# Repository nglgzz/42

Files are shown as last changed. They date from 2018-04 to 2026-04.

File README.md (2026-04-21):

# 42 Keyboard

A mechanical keyboard with 42 keys.

## Features

- 40% – Each key is at most one unit of distance from where the finger that
  should press it rests. In other words there's no awkward reaching for keys
  that are placed far from the home row.
- Staggered columns - Because a comfortable keyboard should follow the shape of
  your hands.
- Low profile - The PCB supports Choc (PG1350) switch mounts as well as Cherry MX/Alps.

## Pics

- Finished keyboard
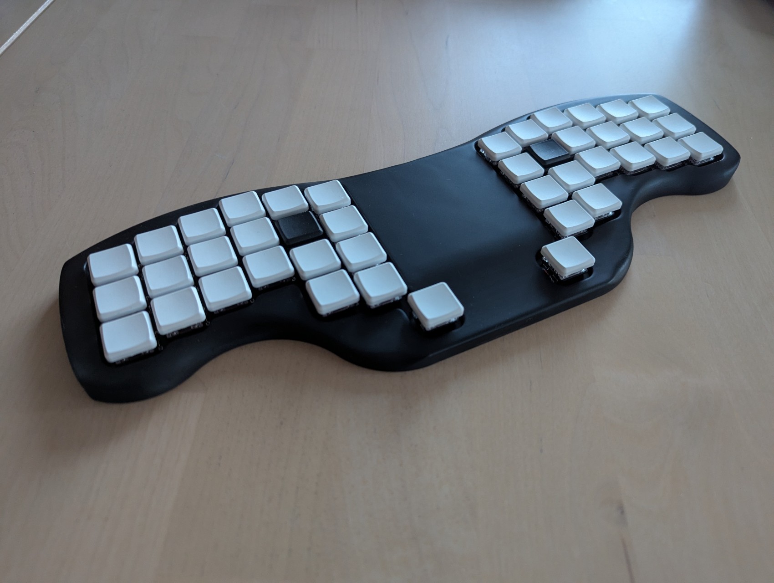
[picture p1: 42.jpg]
  <br/>
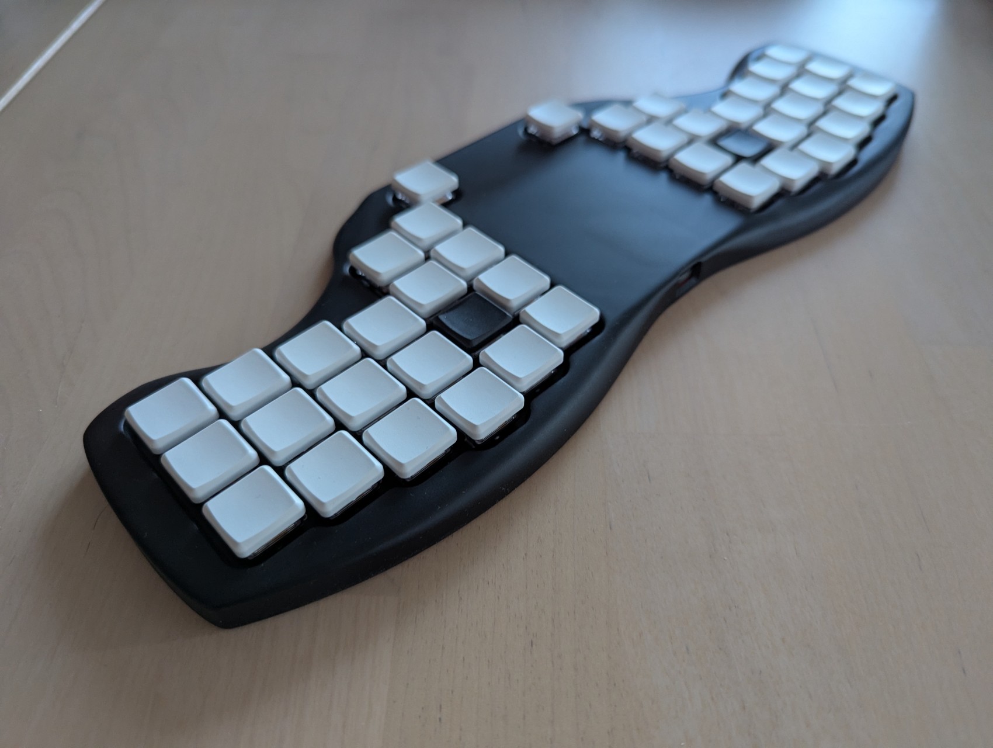
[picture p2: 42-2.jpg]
  <br/>
- PCB
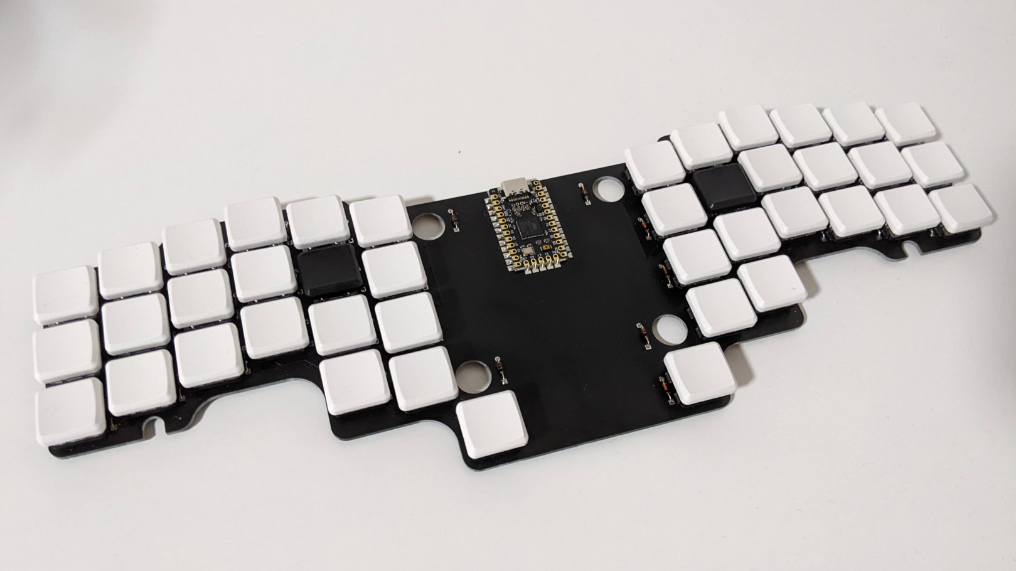
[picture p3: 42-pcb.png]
v3.1 PCB picture
  <br/>

## Project Structure

- [Build](./build/README.md) – Build log, bill of materials, tips on where to
  source parts, assembling tips, learning resources I used while designing this
  keyboard.

- [Case](./case/README.md) – Fusion 360 project and STL files for 3D printing
  the enclosure.

- [Firmware](./firmware/README.md) – QMK configuration. There is a Makefile to
  build and load the firmware.

- [PCB](./pcb/README.md) – Kicad project and Gerber files for manufacturing the
  circuit board.

## Why?

In January 2018 I wanted a keyboard with a specific set of features. The
simplest options to get that keyboard were to wait for a group-buy or build my
own. Waiting time and costs for both options seemed similar, so I went with the
option where I would learn the most.

Needs and knowledge changed over time, so I made different iterations to add new
features and account for the lessons learned from previous builds.

## Feedback

If you have some feedback or questions, feel free to [create an issue](https://github.com/nglgzz/42/issues/new). Your input is more than welcome!

## Previous Versions

- [version 3.1](https://github.com/nglgzz/42/tree/rev-3.1) –
  custom PCB, QMK firmware, USB C, Elite-C v4
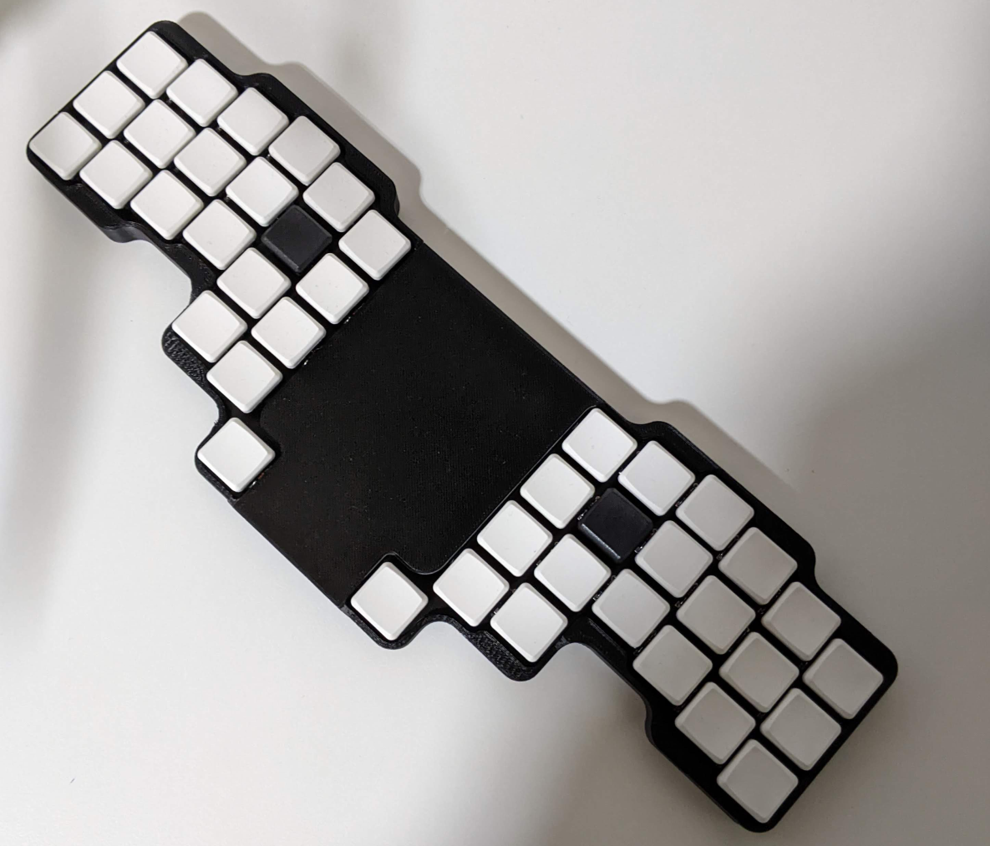
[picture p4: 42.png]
  <br/>
- [version 3](https://github.com/nglgzz/42/tree/rev-3) –
  custom PCB, QMK firmware, Bluetooth, micro USB, Adafruit Feather 32u4 Bluefruit LE
  <br/>v3 picture
- [version 2](https://github.com/nglgzz/42/tree/rev-2) –
  handwired, QMK firmware, Bluetooth, micro USB, Adafruit Feather 32u4 Bluefruit LE
  <br/>v2 picture
- [version 1:](https://github.com/nglgzz/42/tree/rev-1)
  custom PCB, Split, TMK firmware, USB C, Teensy 2.0
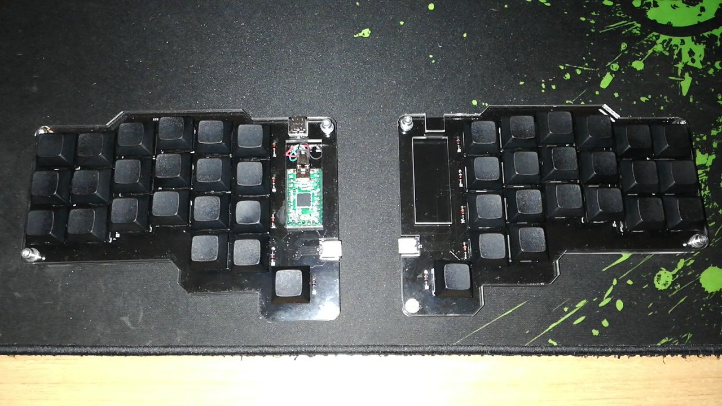
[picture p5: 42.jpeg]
v1 picture
  <br/>

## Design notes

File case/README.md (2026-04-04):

# [42 Keyboard](../README.md) – Case

The enclosure is made of two parts, top and bottom. Each can be 3D printed in
one piece, if your machine has the print volume for it, or they can be printed
in "halves".

When 3D printing I've had the best result by printing the top with organic
supports and at a 45 degree angle (with the thumb keys edge touching the print
bed, and the USB connector edge being furthest away from the print bed).

The top side has holes for M3 (5mm height, 5mm external diameter) heat set
inserts, and the two sides are meant to be assembled with M3x8mm countersunk bolts.

Below is a simplified version of the assembly (missing the micro-controller and
heat set inserts).

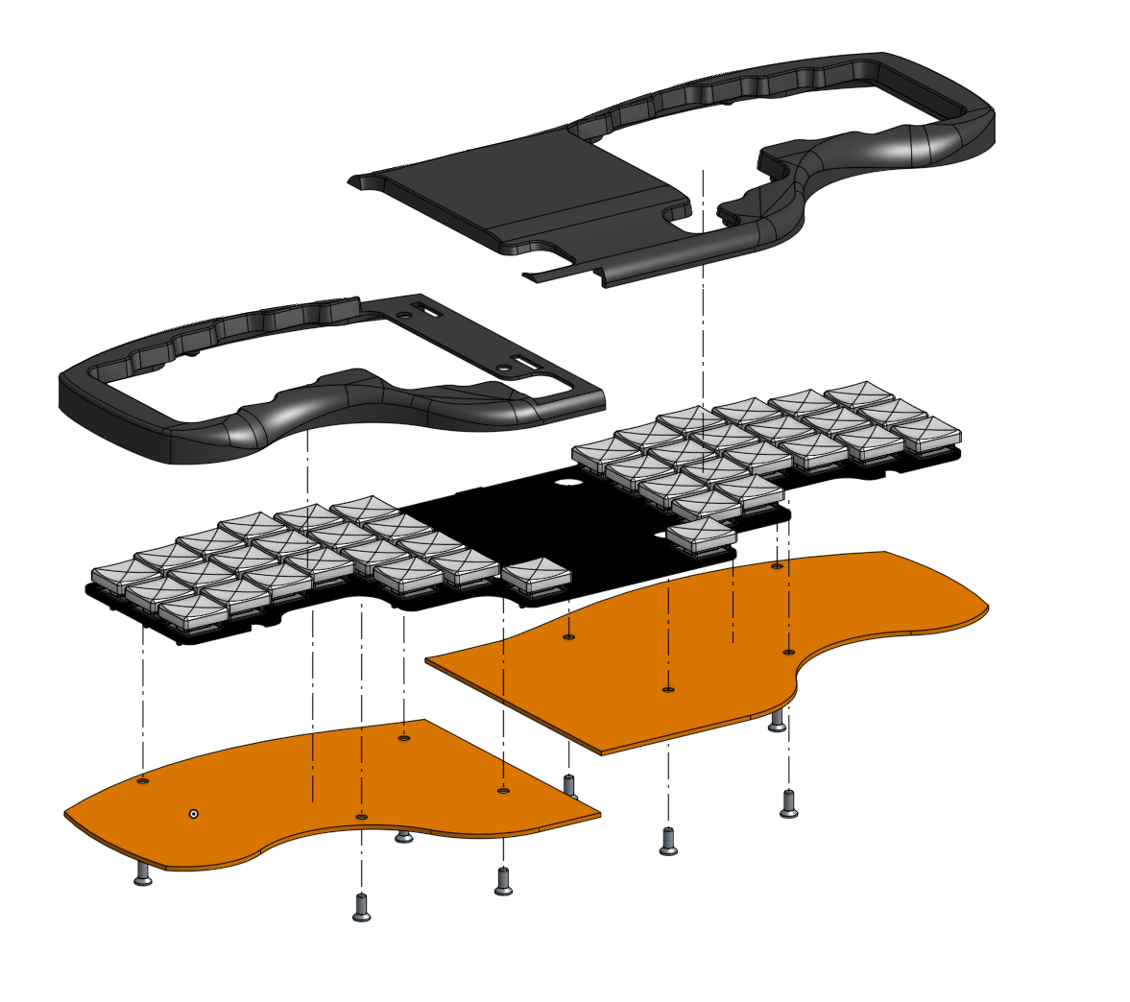
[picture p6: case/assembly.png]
case assembly


## Onshape project

[The Onshape project can be viewed here.](https://cad.onshape.com/documents/cb8004757ac706cd9c775f57/v/824a674918c94d4b9e8f52ce/e/c6679b585992e23092c8d566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)
Through this link you can also export the various parts in different formats and
"fork" the project to make changes to it.

## Bottom plate

Since the bottom is a simple 2D plate, it could be manufactured through laser
cutting instead of 3D printing. I added a .step file for that use case.

Note that if laser cutting, the holes will need to be manually countersunk for
the bolts to sit flush with the bottom of the keyboard. Also if manufacturing
the plate out of sheet metal, an insulation layer between the back of the PCB
and the bottom plate will be needed to prevent short-circuits, and that might
increase the total height of the keyboard.

## Useful Resources

[../build/resources.md](../build/resources.md#case)

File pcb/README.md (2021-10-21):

# [42 Keyboard](../README.md) – PCB

Here you can find the Kicad project for the keyboard's circuit board, and the Gerber files needed to manufacture it.

## Useful Resources

[../build/resources.md](../build/resources.md#pcb)

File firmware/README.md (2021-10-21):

# [42 Keyboard](../README.md) – Firmware

The firmware for this keyboard is also located in the
[QMK repository](https://github.com/qmk/qmk_firmware/tree/master/keyboards/handwired/42).
If you're building it from there (or using other QMK tools), the keyboard is
called `handwired/42`.

## Build

To build and load the firmware into your board, cd into this directory and run:

```
make init
make build
```

The firmware is built for the Elite-C controller. It should work with the Pro
Micro too with no need for changes (I haven't tested though).

## Keymap

The keymap can be adapted in `keymaps/default/keymap.c`, and a legend can be
found on [KeyboardLayoutEditor](https://www.keyboard-layout-editor.com/#/gists/bdcb70e56b88022d86f30f0957648d67).

How to read the labels (L = layer):

```
  /--------------\
  │L0          L1│
  │   L1+Shift L2│
  │L0+Shift    L3│
  \--------------/
   \ dual  role /
```

- L0 – default layer
- L1 – numbers, symbols, F keys
- L2 – navigation and media keys
- L3 – mouse controls
- Dual role: use L0 when tapped quickly, use the value on the front label when kept pressed or used as a modifier

## Useful Resources

[../build/resources.md](../build/resources.md#firmware)

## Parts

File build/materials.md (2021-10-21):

# [42 Keyboard](../README.md) – [Build](README.md) – Materials

The table below lists all the components needed for assembling the keyboard,
their cost at the time of writing, and a link to buy them.

Quantities [in brackets] mean the component is optional.

| Description | Quantity | Cost (EUR) | Link |
| --- | ---: | ---: | --- |
| Mill Max Controller sockets and pins | [1 socket / 24 pins] | 7.74 | [MK Ultra](https://mkultra.click/mill-max-micro-controller-sockets-and-pins/) |
| Switches (Kailh Choc) | 42 | 21.50 | [MK Ultra](https://mkultra.click/choc-switches) |
| Keycaps (Kailh Choc) | 42 | 12.90 | [MK Ultra](https://mkultra.click/mbk-choc-keycaps) |
| 1N4148 diodes | 42 | 5 | [Candy Keys](https://candykeys.com/product/fairchild-semiconductor-diode-1n4148-pack-of-100) |
| Elite C (rev4) | 1 | 19.90 | [Candy Keys](https://candykeys.com/product/elite-c-v4) |
| PCB | 1 | 17.01 | [JLC PCB](https://jlcpcb.com) |
| M3x12 Screws | 6 | - | |
| M3x4 Heat set inserts | 6 | - | |
| Enclosure | 1 | - | |
| . | | | |
| Total (MK Ultra) | | 42.14 | |
| Total (Candy Keys) | | 24.90 | |
| Total (JLC PCB) | | 17.01 | |
| Total | | 84.05 | |

## Notes

- Prices don't include shipping and potential import taxes.
- The minimum order on JLC PCB is 5 circuit boards, so the price above is for 5
  circuit boards.

### If you live in the EU

- JLC PCB offers [DHL Packet European](https://twitter.com/JLCPCB/status/1244461189200920576)
  as a shipping method. It takes between 4-8 business days and you will not be
  charged import taxes as they will ship to you from their European distributor.
  Depending on where in the EU you are located, the cost of PCBs and how much
  you're willing to wait, this might be your best option.
- It's a good idea to check [this page](https://ec.europa.eu/taxation_customs/individuals/buying-goods-services-online-personal-use/buying-goods/buying-goods-online-coming-from-a-noneu-union-country_en)
  and your local customs agency website to get an idea of the fees you'll
  have to pay when ordering from outside the EU.
- QMK suggests to buy the Proton C from mykeyboard.eu if you're in Europe, but
  I've never seen it in stock there. My suggestion is to buy it from
  [/r/mechmarket](https:/reddit/com/r/mechmarket), or order it from the US.

## Alternatives

- Switches, keycaps, and cables – plenty of resellers are listed in the
  [/r/MechanicalKeyboards Wiki](https://www.reddit.com/r/MechanicalKeyboards/wiki/recommendedsellers).

- PCBs – In my experience JLC PCB was always the cheapest option, but that might
  be different depending on where you are located. You can check
  [PCB Shopper](https://pcbshopper.com/) to compare PCB manufacturers in your
  location.

## Disclaimer

I'm in no way affiliated with any of the sellers/manufacturers mentioned here.

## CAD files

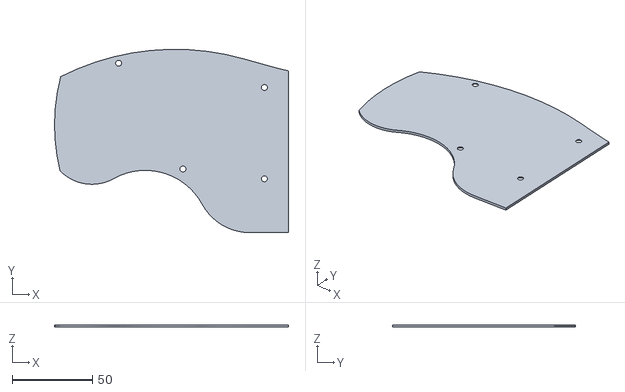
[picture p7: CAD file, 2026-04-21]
case/bottom-left.stl
146.1 x 114.4 x 1.50

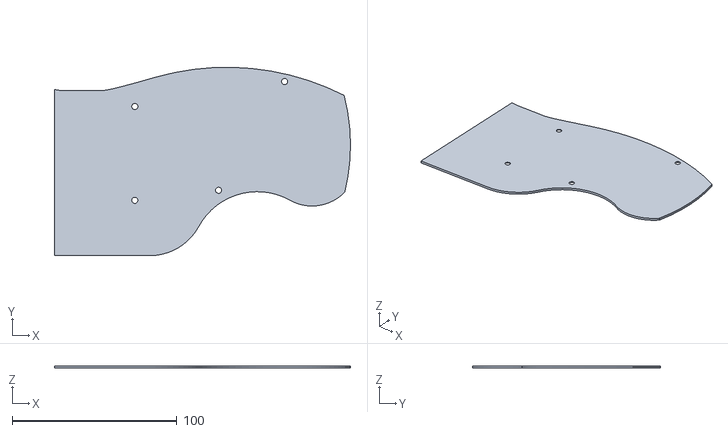
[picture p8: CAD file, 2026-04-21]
case/bottom-right.stl
179.8 x 114.4 x 1.50

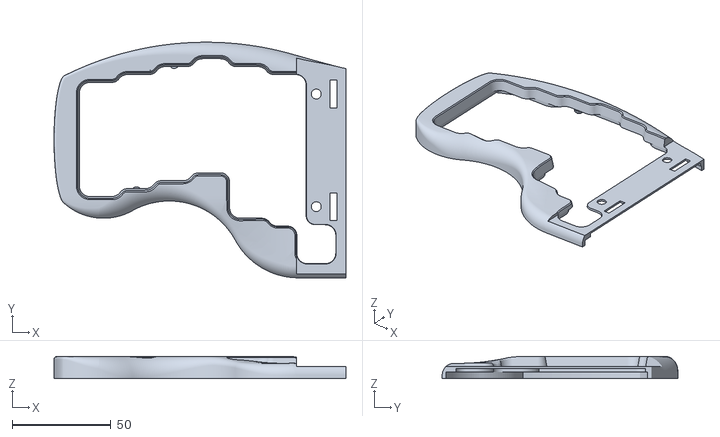
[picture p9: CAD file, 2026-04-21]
case/top-left.stl
147.8 x 119.2 x 11.2

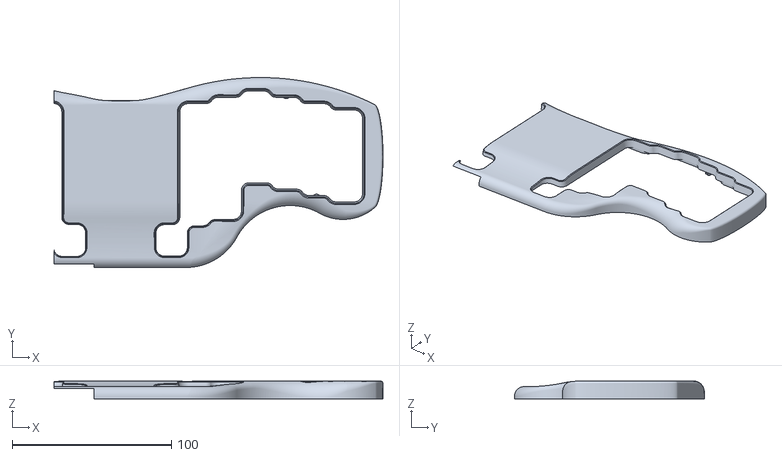
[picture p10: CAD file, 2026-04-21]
case/top-right.stl
206.6 x 119.2 x 11.2

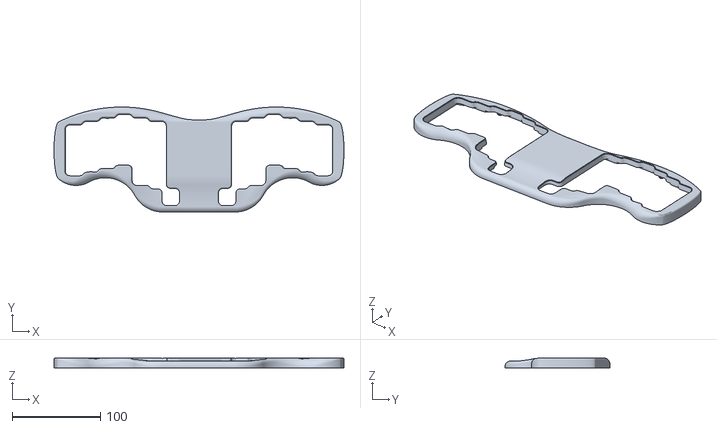
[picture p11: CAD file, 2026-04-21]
case/top.stl
329.5 x 119.2 x 11.2

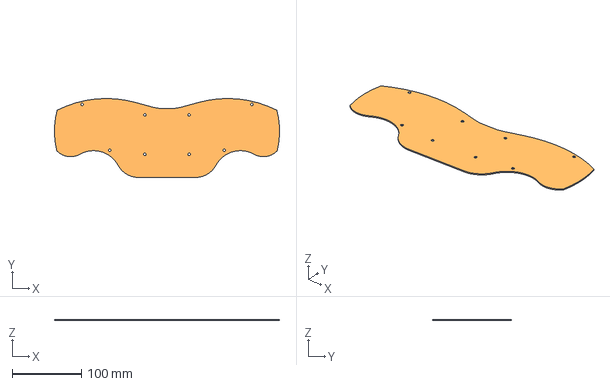
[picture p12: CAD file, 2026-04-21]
case/bottom.step
325.8 x 114.4 x 1.50 mm

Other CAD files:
case/bottom.stl

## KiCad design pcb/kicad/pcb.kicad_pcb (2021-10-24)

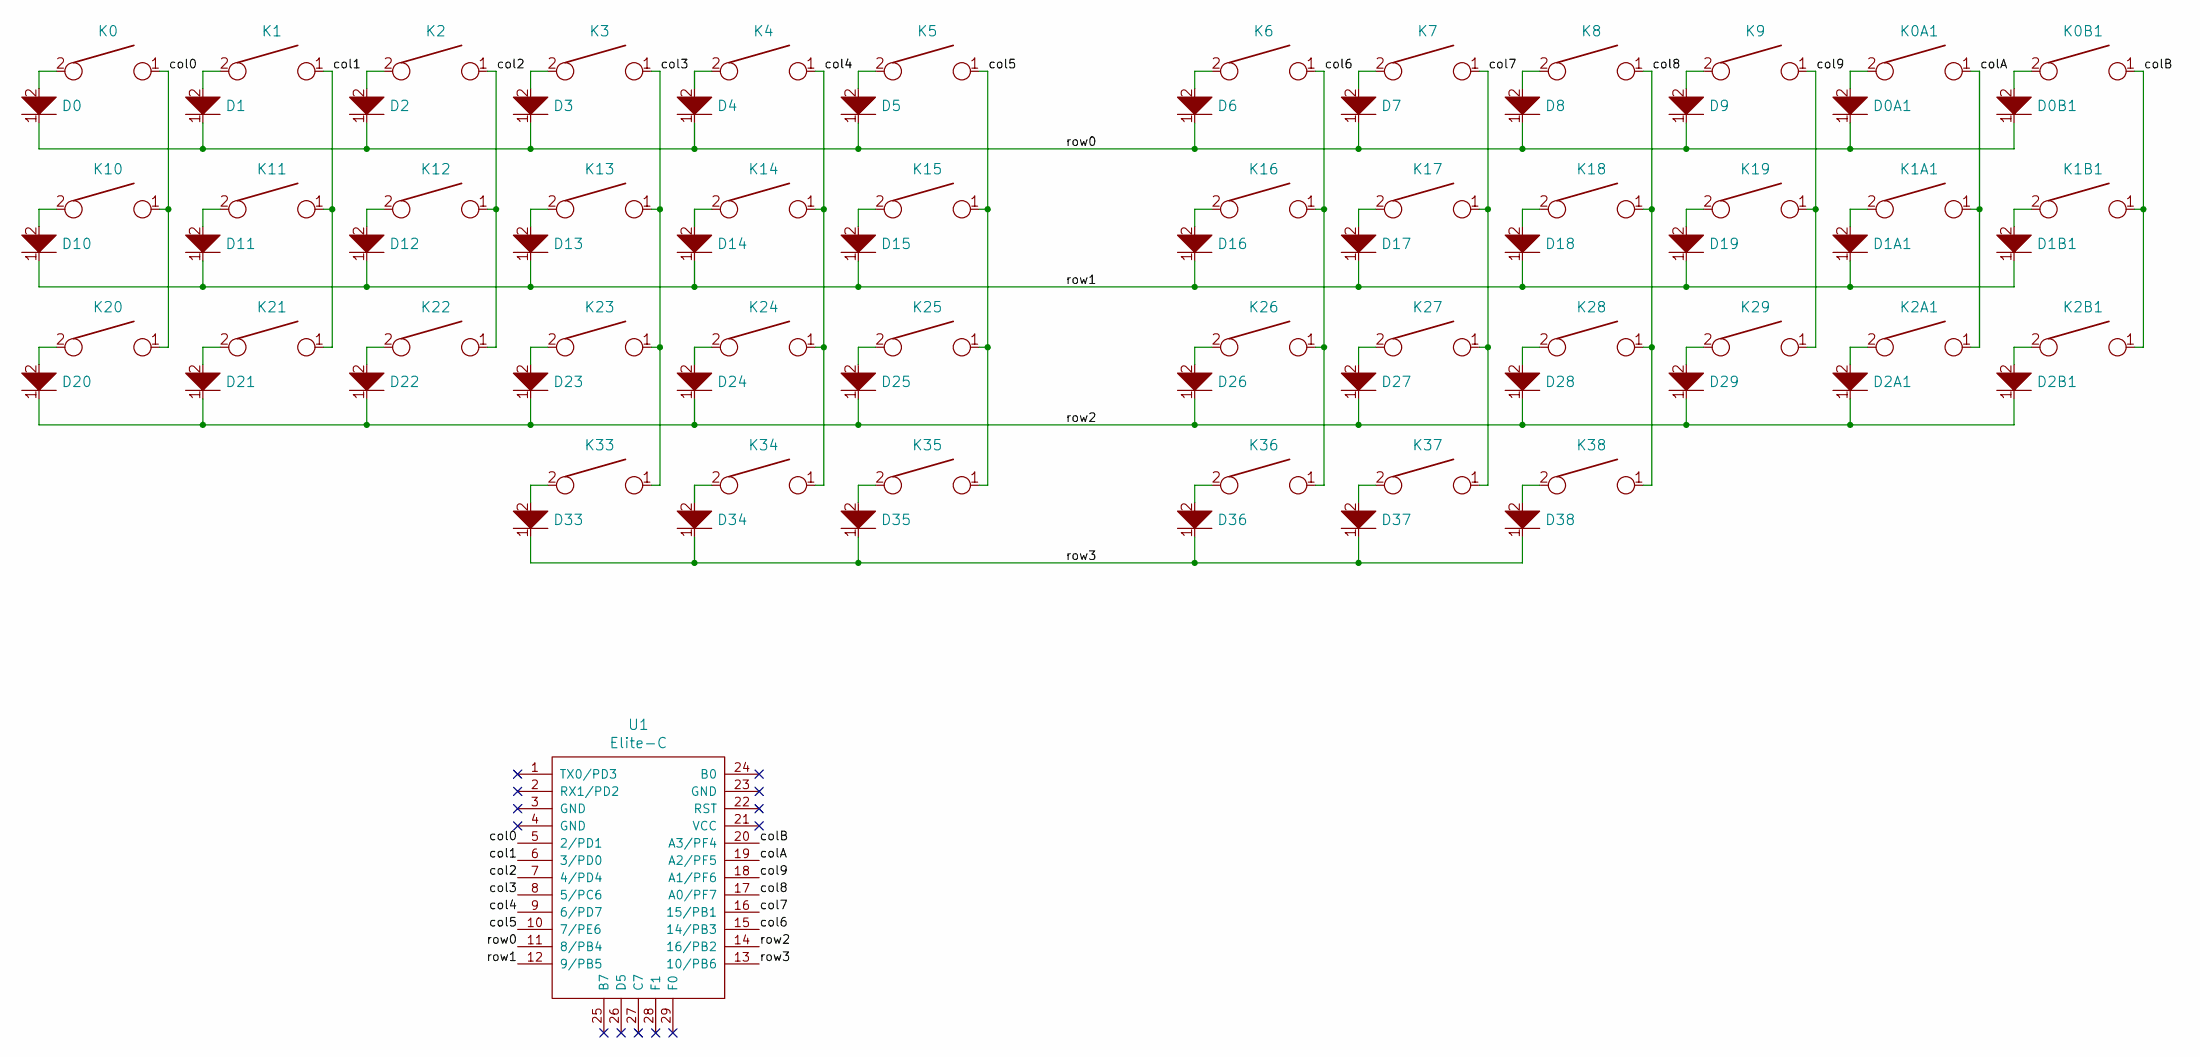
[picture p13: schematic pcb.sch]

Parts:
D0, D0A1, D0B1, D1, D1A1, D1B1, D2, D2A1, D2B1, D3, D4, D5, D6, D7, D8, D9, D10, D11, D12, D13, D14, D15, D16, D17, D18, D19, D20, D21, D22, D23, D24, D25, D26, D27, D28, D29, D33, D34, D35, D36, D37, D38: D; D_SOD123_axial
K0, K0A1, K0B1, K1, K1A1, K1B1, K2, K2A1, K2B1, K3, K4, K5, K6, K7, K8, K9, K10, K11, K12, K13, K14, K15, K16, K17, K18, K19, K20, K21, K22, K23, K24, K25, K26, K27, K28, K29, K33, K34, K35, K36, K37, K38: KEYSW; MX-Alps-Choc-1U-NoLED
U1: Elite-C; Elite-C-castellated-29pin-holes

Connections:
/col0: K0.1, K10.1, K20.1, U1.5 (2/PD1)
/col1: K1.1, K11.1, K21.1, U1.6 (3/PD0)
/col2: K2.1, K12.1, K22.1, U1.7 (4/PD4)
/col3: K3.1, K13.1, K23.1, K33.1, U1.8 (5/PC6)
/col4: K4.1, K14.1, K24.1, K34.1, U1.9 (6/PD7)
/col5: K5.1, K15.1, K25.1, K35.1, U1.10 (7/PE6)
/col6: K6.1, K16.1, K26.1, K36.1, U1.15 (14/PB3)
/col7: K7.1, K17.1, K27.1, K37.1, U1.16 (15/PB1)
/col8: K8.1, K18.1, K28.1, K38.1, U1.17 (A0/PF7)
/col9: K9.1, K19.1, K29.1, U1.18 (A1/PF6)
/colA: K0A1.1, K1A1.1, K2A1.1, U1.19 (A2/PF5)
/colB: K0B1.1, K1B1.1, K2B1.1, U1.20 (A3/PF4)
/row0: D0.1, D0A1.1, D0B1.1, D1.1, D2.1, D3.1, D4.1, D5.1, D6.1, D7.1, D8.1, D9.1, U1.11 (8/PB4)
/row1: D1A1.1, D1B1.1, D10.1, D11.1, D12.1, D13.1, D14.1, D15.1, D16.1, D17.1, D18.1, D19.1, U1.12 (9/PB5)
/row2: D2A1.1, D2B1.1, D20.1, D21.1, D22.1, D23.1, D24.1, D25.1, D26.1, D27.1, D28.1, D29.1, U1.14 (16/PB2)
/row3: D33.1, D34.1, D35.1, D36.1, D37.1, D38.1, U1.13 (10/PB6)
unnamed: D0.2, K0.2
unnamed: D0A1.2, K0A1.2
unnamed: D0B1.2, K0B1.2
unnamed: D1.2, K1.2
unnamed: D1A1.2, K1A1.2
unnamed: D1B1.2, K1B1.2
unnamed: D2.2, K2.2
unnamed: D2A1.2, K2A1.2
unnamed: D2B1.2, K2B1.2
unnamed: D3.2, K3.2
unnamed: D4.2, K4.2
unnamed: D5.2, K5.2
unnamed: D6.2, K6.2
unnamed: D7.2, K7.2
unnamed: D8.2, K8.2
unnamed: D9.2, K9.2
unnamed: D10.2, K10.2
unnamed: D11.2, K11.2
unnamed: D12.2, K12.2
unnamed: D13.2, K13.2
unnamed: D14.2, K14.2
unnamed: D15.2, K15.2
unnamed: D16.2, K16.2
unnamed: D17.2, K17.2
unnamed: D18.2, K18.2
unnamed: D19.2, K19.2
unnamed: D20.2, K20.2
unnamed: D21.2, K21.2
unnamed: D22.2, K22.2
unnamed: D23.2, K23.2
unnamed: D24.2, K24.2
unnamed: D25.2, K25.2
unnamed: D26.2, K26.2
unnamed: D27.2, K27.2
unnamed: D28.2, K28.2
unnamed: D29.2, K29.2
unnamed: D33.2, K33.2
unnamed: D34.2, K34.2
unnamed: D35.2, K35.2
unnamed: D36.2, K36.2
unnamed: D37.2, K37.2
unnamed: D38.2, K38.2

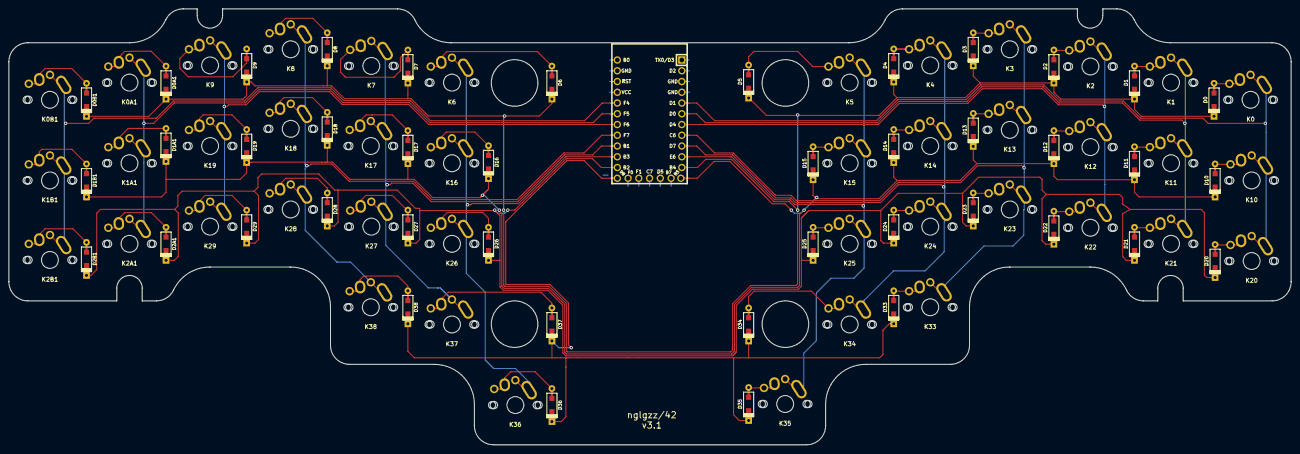
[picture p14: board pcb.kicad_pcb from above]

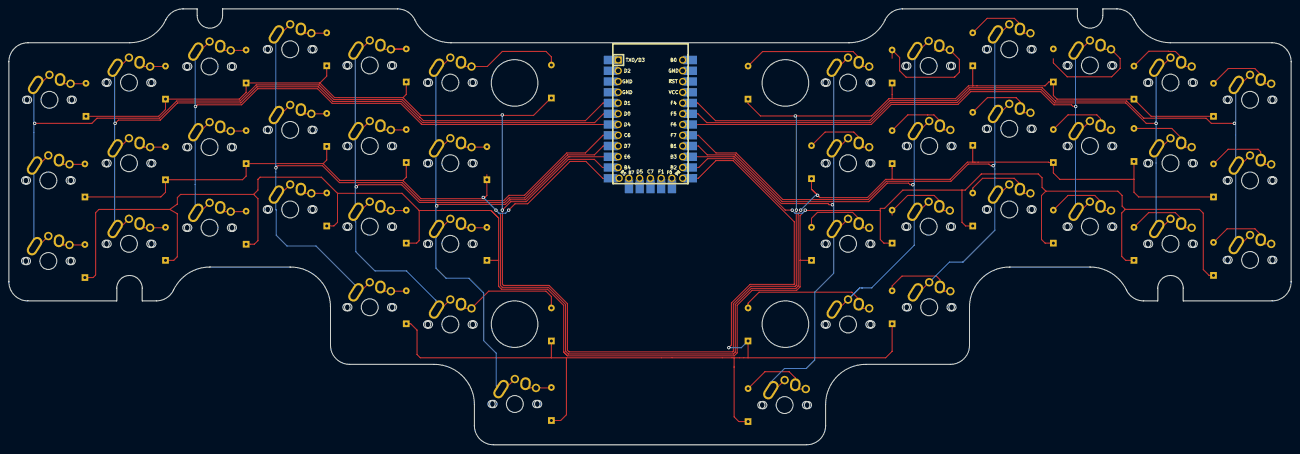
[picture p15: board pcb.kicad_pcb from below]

Board: 2 copper layers, 303.0 x 103.0 mm, 85 parts (43 on the bottom side), 58 nets.

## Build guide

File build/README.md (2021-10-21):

# [42 Keyboard](../README.md) – Build

Everything that is related to assembling or designing the keyboard.

- [Materials](./materials.md) – Bill of materials and tips on buying parts.

- [Build log](./build-log.md) – Build log and assembling tips.

- [Resources](./resources.md) – Learning resources I used while designing
  and building this keyboard.

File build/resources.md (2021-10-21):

# [42 Keyboard](../README.md) – [Build](./README.md) – Resources

Here is a list of the resources I found most useful while designing and building
the keyboard.

## General

- [/r/MechanicalKeyboards Wiki](https://www.reddit.com/r/MechanicalKeyboards/wiki/customkeyboards) –
  The most complete keyboard wiki I found so far. Most links in this list are there too.

## Firmware

- [QMK Docs](https://docs.qmk.fm/#/) –
  Guides and documentation for configuring the QMK firmware for your keyboard.
  The content is easy to follow and they cover most use cases.

- [QMK Firmware](https://github.com/qmk/qmk_firmware/) –
  If something wasn't in the docs, or it was not clear, reading code from other
  keyboards helped understanding it. Clone the repository locally and search the
  codebase for keywords if you want to see examples. Just keep in mind not all
  keyboards are up to date.

- [How to make a keyboard: The Matrix](http://blog.komar.be/how-to-make-a-keyboard-the-matrix/) –
  Explains starting from basic electronics concepts, how a keyboard matrix
  works. It's a fascinating read even though in most cases you don't need to
  know this.

- [Testing and Debugging QMK](https://beta.docs.qmk.fm/tutorial/newbs_testing_debugging#debugging-with-hid_listen) –
  Useful to know what's going on in the firmware if you're actually touching the
  firmware code.

## PCB

- [A modern handwiring guide](https://geekhack.org/index.php?topic=87689.0) –
  It helps understanding how a keyboard is wired. Useful even if you end up
  designing a PCB.

- [Keyboard PCB Guide](https://github.com/ruiqimao/keyboard-pcb-guide) –
  A step-by-step guide on designing a PCB using Kicad. You might need to search for
  some things that are not covered here (eg. how to create a footprint), but the
  basics are all covered.

- [daprice/keyswitches.pretty](https://github.com/daprice/keyswitches.pretty) –
  Not a learning resource. Footprint library for a bunch of different switch sockets.

- [Why split keyboards don't use USB](https://www.reddit.com/r/MechanicalKeyboards/comments/a641ls/split_keyboard_trrs_shorting_and_protection/ebryvx5) –
  In-depth explanation why TRRS has become the standard for split keyboards. I
  wish I have read this before going with USB-C on my first keyboard.

- [Elite C Pinout](https://deskthority.net/wiki/Elite-C)

## Case

- [Fusion 360 Tutorial for Absolute Beginners](https://www.youtube.com/watch?v=A5bc9c3S12g) –
  I spent a long time trying to design the enclosure with awkward-to-use tools.
  Until I found and instantly fell in love with Fusion 360. Once you learn the
  basics, you'll see how incredibly intuitive yet powerful this software is.

## Help

- [/r/MechanicalKeyboards](https://www.reddit.com/r/MechanicalKeyboards/) –
  Many of my Google searches ended up on threads from this subreddit. If you get
  stuck, this seems like a great place to ask.

- [QMK Discord Server](https://discord.gg/Uq7gcHh) –
  I had no idea if what I wanted to achieve was supported in QMK and the QMK
  devs pointed me in the right direction here. They also have some channels for
  more entry level questions in case you get stuck while following their
  documentation.

## Disclaimer

I'm in no way affiliated with any of the resources mentioned here.

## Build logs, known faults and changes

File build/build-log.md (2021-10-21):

# [42 Keyboard](../README.md) – [Build](./README.md) – Log

Coming soon.

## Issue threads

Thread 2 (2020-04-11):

Case: finish enclosure for v4

nglgzz, 2020-04-11:
Things I'm missing for the enclosure:

- [x] Share Fusion 360 project ([available here](https://github.com/nglgzz/42/blob/master/case/README.md))
- [x] Figure out if it's better to have an extra component for the connector, or if it should be part of one of the halves (currently it's an extra component).
- [x] Add bottom lid
- [x] Add holes for M3 screws
- [ ] Add screws to list of materials (and heat set inserts)
- [ ] Add STL models of all components
- [x] Update case/README.md

Early render:
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

nglgzz, 2020-04-12:
Having one of the halves be the connector makes for a sturdier assembly, a cleaner look, and makes it easier to switch between split/one-piece modes.

3D printing the new model requires more careful cleanup, as some of the supports are slightly awkward to reach, but nothing too difficult.

nglgzz, 2020-04-17:
The case is almost finished. Waiting on the set inserts and new magnets to finalize the design.

Closed 2020-04-25.

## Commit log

2018-03-11 added case and gerber files
    [42-B.Cu.gbr, 42-B.Mask.gbr, 42-B.SilkS.gbr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]
2018-03-11 added kicad project
    [42.kicad_pcb, 42.sch]
2018-03-11 rounded case corners
    [all-layers.dxf, top-left.dxf, top-right.dxf]
2018-03-13 fixed position of thumb key footprint
    [42.kicad_pcb]
2018-03-13 removed controller and usb receptacle holes from right side
    [all-layers.dxf]
2018-03-14 fixed inverted connections on USB receptacle
    [42.kicad_pcb, 42.sch]
2018-03-26 rounded corners, ignore backup saves
    [42.kicad_pcb]
2018-03-26 moved receptacles to the back side, rewired connections
    [42.kicad_pcb, 42.sch]
2018-03-29 updated gerber files
    [42-B.Cu.gbr, 42-B.Mask.gbr, 42-B.SilkS.gbr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]
2018-05-20 update case
    [all-layers.dxf, top-left.dxf, top-right.dxf]
2018-06-02 update case files, add gaming mode
    [all-layers.stl, bottom-left.stl, bottom-right.stl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]
2019-02-03 Add v2 files
    [42-B.Cu.gbr, 42-B.Mask.gbr, 42-B.SilkS.gbr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]
2019-05-13 Case: model version 3
    [bottom-left.stl, bottom-right.stl, bottom.stl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]
2019-06-06 PCB: add kicad and gerber files
    [pcb-B_Cu.gbl, pcb-B_Mask.gbs, pcb-B_Paste.gbp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]
2019-06-08 PCB: add hole for battery cables
    [pcb-B_Cu.gbl, pcb-B_Mask.gbs, pcb-B_Paste.gbp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]
2019-06-20 Case: update STL files
    [bottom-left.stl, bottom-right.stl, bottom.stl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]
2019-06-20 Case: update readme
2021-10-17 Redesign PCB for Elite-C
    [pcb.kicad_pcb]
2021-10-17 Add support for Choc v1 switches
    [pcb.kicad_pcb, pcb.sch]
2021-10-21 Add PCB support for Pro Micro
    [pcb.kicad_pcb, pcb.sch]
2021-10-24 Update gerber files
    [pcb-B_Cu.gbl, pcb-B_Mask.gbs, pcb-B_Paste.gbp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]
2022-01-17 Add STL files for case
    [bottom-left.stl, bottom-right.stl, bottom.stl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]
2026-04-04 Update case files and description
    [bottom-left.stl, bottom-right.stl, bottom.step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]
2026-04-21 Update case front fillet and connector recess
    [bottom-left.stl, bottom-right.stl, bottom.step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]
2026-06-04 Switch to liatris board
